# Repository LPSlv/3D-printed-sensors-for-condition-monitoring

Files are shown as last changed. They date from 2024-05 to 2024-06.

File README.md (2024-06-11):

# 3D Printed Sensors for Electric Motor Condition Monitoring

## Overview

This project focuses on developing a method for using 3D printed electrically conductive material sensors to monitor the condition of an electric motor. The study yielded 40 datasets containing time series data of deformations caused by vibrations in 10 different electric motors. Three conditions were monitored:
1. Worn or new motor
2. Cracked or intact motor mount
3. Wheel attached or detached from the motor shaft

Features were extracted from the signals using power spectral density and used for classification with the Random Forest method. The results showed feature separation between used and unused motor conditions, achieving 79% accuracy and 88% recall.

## Key Metrics

| Class | Accuracy | Precision | Recall | F1 Score |
|---|---|---|---|---|
| Worn Motor | 0.788 | 0.817 | 0.875  | 0.804 |
| Cracked Mount | 0.688 | 0.667 | 0.542  | 0.567 |
| Wheel Attached | 0.513 | 0.467 | 0.667  | 0.542 |

## Sensor Design

Based on the literature review, a 3D printed resistance sensor was developed using Proto-pasta's electrically conductive material. The sensor specifications are:
- Active part length: 12 mm
- Thickness: 0.6 mm
- Trace width: 1.6 mm
- Base thickness: 0.1 mm
- Unstressed resistance: ~4.2 kΩ
- Theoretical maximum measurement frequency: 13.6 kHz

## Data Collection

An Arduino Leonardo and a voltage divider circuit were used for data collection.

## Experimentation

Using the developed 3D printed sensor, data collection circuit, and Pololu micro metal gearmotors with controllers, measurements of deformations caused by motor vibrations were conducted. The obtained datasets consisted of at least 60-second long time series data for various motor condition combinations: worn motor, cracked motor mount, and attached wheel.

## Classification

To test the applicability of the developed sensor and measurement scheme for condition monitoring, a Random Forest classification was performed using power spectral density for feature extraction. The analysis indicated feature separation for the worn motor class, while other classes showed overlap. The classification metrics are summarized in the table above, with the worn motor class showing the highest performance.

## Conclusion

The developed 3D printed sensor and measurement scheme can be used to determine motor wear. The high recall metric indicates potential applications in scenarios where failure to detect motor damage could lead to significant system damage or safety risks. 

## Future Work

Further research is needed to:
1. Improve the reliability of 3D printed sensor results to reduce the number of invalid datasets, such as enhancing the electrical connections between the sensor and measurement scheme.
2. Explore other feature extraction methods and algorithms to improve classification for other conditions. This could include calculating additional features or using other machine learning algorithms.

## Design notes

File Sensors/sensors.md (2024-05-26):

A sensor was developed with trace width of 1.6 mm, an active length of 12 mm, and a single end loop. The sensor thickness was maintained at 0.6 mm for the active part and 0.1 mm for the base. Theoretically, this sensor can measure frequencies up to 13.6 kHz and has an electrical resistance of approximately 4.2 kΩ in an unstressed state.

Two different materials were used to manufacture the sensors:

1. **Proto-Pasta Conductive PLA** for the electrically conductive part of the sensor.
2. **Colorfabb PLA** for the electrically non-conductive base part.

**Printing Parameters**:

- **Layer height**: 0.3 mm
- **Infill**: 100%
- **Printing temperature**: 230°C
- **Printing speed**: 200 mm/s
- **Perimeter walls**: 2
- **Bed temperature**: 50°C

Other settings were selected based on printer defaults or material manufacturer recommendations.

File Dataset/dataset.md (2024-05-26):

Overall, 40 experiments were conducted, resulting in 40 data sets, each measuring different combinations of the electric motor system state. Measurements were taken for approximately 60 seconds for each data set. 10 Pololu micrometal gearmotors were used, of which 6 were worn out and 4 were new or slightly used. To test the sensor's ability to monitor various states of the electric motor system, the following states were selected:

1. **Added load** – an aluminum wheel with a diameter of 26 mm and a width of 20 mm attached to the motor shaft.
2. **Structural integrity** – a cracked 3D-printed mount used for motor mounting.
3. **Motor wear** – whether the motor is worn, such as an eccentric shaft rotation.

| Nr. | File name | Wheel added | Broken mount | Worn out motor |
|-----|---|---|---|---|
| 1 | 16_May_15h_41m_5.0V_2.2kOhm_log.csv  | 1 | 1 | 1 |
| 2 | 16_May_15h_43m_5.0V_2.2kOhm_log.csv  | 0 | 1 | 1 |
| 3 | 16_May_15h_49m_5.0V_2.2kOhm_log.csv  | 1 | 0 | 1 |
| 4 | 16_May_15h_47m_5.0V_2.2kOhm_log.csv  | 0 | 0 | 1 |
| 5 | 16_May_16h_00m_5.0V_2.2kOhm_log.csv  | 1 | 1 | 1 |
| 6 | 16_May_15h_58m_5.0V_2.2kOhm_log.csv  | 0 | 1 | 1 |
| 7 | 16_May_16h_04m_5.0V_2.2kOhm_log.csv  | 1 | 0 | 1 |
| 8 | 16_May_16h_06m_5.0V_2.2kOhm_log.csv  | 0 | 0 | 1 |
| 9 | 16_May_16h_13m_5.0V_2.2kOhm_log.csv  | 1 | 1 | 1 |
| 10  | 16_May_16h_10m_5.0V_2.2kOhm_log.csv  | 0 | 1 | 1 |
| 11  | 16_May_16h_16m_5.0V_2.2kOhm_log.csv  | 1 | 0 | 1 |
| 12  | 16_May_16h_20m_5.0V_2.2kOhm_log.csv  | 0 | 0 | 1 |
| 13  | 16_May_16h_27m_5.0V_2.2kOhm_log.csv  | 1 | 1 | 0 |
| 14  | 16_May_16h_25m_5.0V_2.2kOhm_log.csv  | 0 | 1 | 0 |
| 15  | 16_May_17h_09m_5.0V_2.2kOhm_log.csv  | 1 | 0 | 0 |
| 16  | 16_May_16h_58m_5.0V_2.2kOhm_log.csv  | 0 | 0 | 0 |
| 17  | 16_May_17h_30m_5.0V_2.2kOhm_log.csv  | 1 | 1 | 0 |
| 18  | 16_May_17h_28m_5.0V_2.2kOhm_log.csv  | 0 | 1 | 0 |
| 19  | 16_May_17h_33m_5.0V_2.2kOhm_log.csv  | 1 | 0 | 0 |
| 20  | 16_May_17h_35m_5.0V_2.2kOhm_log.csv  | 0 | 0 | 0 |
| 21  | 16_May_17h_46m_5.0V_2.2kOhm_log.csv  | 1 | 1 | 1 |
| 22  | 16_May_17h_44m_5.0V_2.2kOhm_log.csv  | 0 | 1 | 1 |
| 23  | 16_May_17h_55m_5.0V_2.2kOhm_log.csv  | 1 | 0 | 1 |
| 24  | 16_May_17h_57m_5.0V_2.2kOhm_log.csv  | 0 | 0 | 1 |
| 25  | 16_May_18h_08m_5.0V_2.2kOhm_log.csv  | 1 | 1 | 1 |
| 26  | 16_May_18h_06m_5.0V_2.2kOhm_log.csv  | 0 | 1 | 1 |
| 27  | 16_May_18h_12m_5.0V_2.2kOhm_log.csv  | 1 | 0 | 1 |
| 28  | 16_May_18h_14m_5.0V_2.2kOhm_log.csv  | 0 | 0 | 1 |
| 29  | 16_May_18h_19m_5.0V_2.2kOhm_log.csv  | 1 | 1 | 1 |
| 30  | 16_May_18h_18m_5.0V_2.2kOhm_log.csv  | 0 | 1 | 1 |
| 31  | 16_May_18h_22m_5.0V_2.2kOhm_log.csv  | 1 | 0 | 1 |
| 32  | 16_May_18h_24m_5.0V_2.2kOhm_log.csv  | 0 | 0 | 1 |
| 33  | 16_May_17h_20m_5.0V_2.2kOhm_log.csv  | 1 | 1 | 0 |
| 34  | 16_May_17h_22m_5.0V_2.2kOhm_log.csv  | 0 | 1 | 0 |
| 35  | 16_May_17h_14m_5.0V_2.2kOhm_log.csv  | 1 | 0 | 0 |
| 36  | 16_May_17h_05m_5.0V_2.2kOhm_log.csv  | 0 | 0 | 0 |
| 37  | 16_May_18h_32m_5.0V_2.2kOhm_log.csv  | 1 | 1 | 0 |
| 38  | 16_May_18h_28m_5.0V_2.2kOhm_log.csv  | 0 | 1 | 0 |
| 39  | 16_May_18h_35m_5.0V_2.2kOhm_log.csv  | 1 | 0 | 0 |
| 40  | 16_May_18h_36m_5.0V_2.2kOhm_log.csv  | 0 | 0 | 0 |

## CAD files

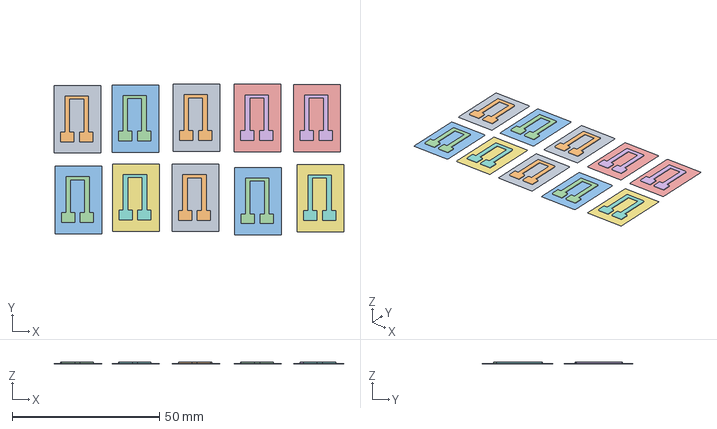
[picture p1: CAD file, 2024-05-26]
Sensors/finalsensor_multimaterial.3mf
98.5 x 51.3 x 0.6 mm
sensorv5_base.stl x 10
sensorv5_top.stl x 10

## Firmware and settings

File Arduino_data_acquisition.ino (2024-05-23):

const int analog_pin = A0;
const unsigned long sampling_interval = 50;
int sensor_value = 0;

void setup() {
  analogReference(DEFAULT);
  Serial.begin(115200);
}

void loop() {
  static unsigned long last_sample_time = 0;
  unsigned long current_time = micros();

  // Pārbauda vai ir pagājis mērījumu intervāls
  if (current_time - last_sample_time >= sampling_interval) {
    sensor_value = analogRead(analog_pin);
    
    // Vērtības nosūtīšana 2 baitos
    Serial.write((uint8_t*)&sensor_value, 2);

    last_sample_time = current_time;
  }
}

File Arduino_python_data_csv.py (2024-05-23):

import serial
import csv
import time
import struct

arduino = serial.Serial('COM11', 115200)

# Dati faila nosaukumam
current_date = time.strftime('%d_%B')
current_time = time.strftime('%Hh_%Mm')
voltage = float(input("Voltage: (V): "))
shunt_resistance = float(input("Shunt resistor (kOhm): "))
filename = f"{current_date}_{current_time}_{voltage}V_{shunt_resistance}kOhm_log.csv"

buffer_size = 100


with open(filename, 'w', newline='') as file:
    data_writer = csv.writer(file)
    
    # Faila galvene
    data_writer.writerow(['Microseconds', 'Value'])
    
    buffer = []

    try:
        print(f"Filename: {filename}...")
        print(f"CTRL+C to stop")
        
        start_time_ns = time.perf_counter_ns()

        while True:
            # Nolasa 2 baitus
            data = arduino.read(2)
            try:
                # Little-endian, unsigned short formats
                sensor_value = struct.unpack('<H', data)[0]  
                
                # Laiks, kas pagajis kops merijuma saksanas
                elapsed_time_ns = time.perf_counter_ns() - start_time_ns
                elapsed_time_us = elapsed_time_ns // 1000
                
                buffer.append([elapsed_time_us, sensor_value])

                # Ja buferis ir pilns, ieraksta datus faila
                if len(buffer) >= buffer_size:
                    data_writer.writerows(buffer)
                    buffer = []

                print(f"Microseconds: {elapsed_time_us}, Value: {sensor_value}")
                
            except KeyboardInterrupt:
                if buffer:
                    data_writer.writerows(buffer)
                arduino.close()
                print("Stopped")
                break
    except serial.SerialException as e:
        print(f"Serial error: {e}")
